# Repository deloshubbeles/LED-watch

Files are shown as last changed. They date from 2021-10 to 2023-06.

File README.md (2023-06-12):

# LED Watch

### Objective
To display the time and day of week on multiplexed LEDs with button presses, plus more.

**Other intended functionality (yet to be implemented)**
- Low power sleep mode to conserve power when inactive
- Flash low battery warning LED when battery voltage drops too low
- Display LEDs at different brightnesses depending on time of day or button pressed (e.g., brighter in daylight, dimmer at night)
- Stopwatch
- Countdown timer

### Displaying the time
time

### Components
- [ATmega328P-MMHR (28-pin VQFN)](https://ww1.microchip.com/downloads/en/DeviceDoc/ATmega48A-PA-88A-PA-168A-PA-328-P-DS-DS40002061B.pdf)
- [M41T62 (8 pin LCC) real time clock](https://www.st.com/resource/en/datasheet/m41t62.pdf)
- 34 multiplexed LEDs (18 red, 12 blue, 4 white)
- CR2016 coin cell battery (~90mAh) and battery holder
- 2 x SPST tactile switches

### Schematic


### PCB layers:
Watch layers

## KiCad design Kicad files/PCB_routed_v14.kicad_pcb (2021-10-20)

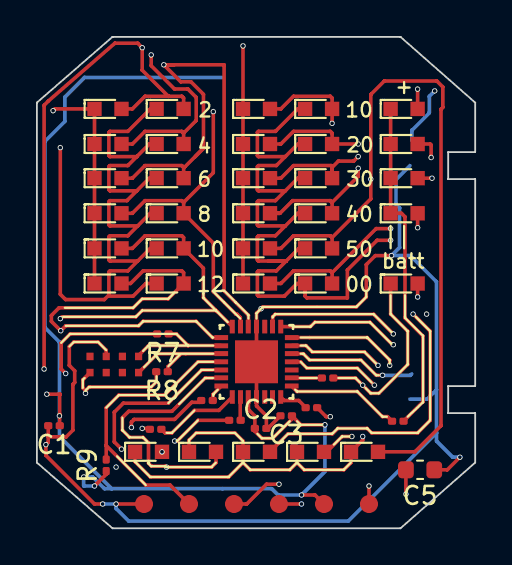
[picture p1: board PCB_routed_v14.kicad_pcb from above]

Board: 4 copper layers, 24.3 x 27.3 mm, 53 parts (0 on the bottom side), 28 nets.

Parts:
BAT1: CR2016
C1, C3: 100nF; C_0201_0603Metric
C2: 10nF; C_0201_0603Metric
C5: 22uF; C_0603_1608Metric
D1, D2, D3, D4, D5, D6, D7, D8, D9, D10, D11, D12: RED_HR; LED_0603
D13, D14, D15, D16, D17, D18, D19, D20, D21, D22, D23, D24: BLUE_MIN; LED_0603
D25, D26, D27, D28: WHITE_+MIN; LED_0603
D29, D30, D31, D32, D33: RED_DAY; LED_0603
D34: RED_BATT; LED_0603
IC1: M41T62LC6F; LCC90P230X50X80-8N
J1: ICSP-6; ICSP
R1, R2, R6: 2K5; R_0201_0603Metric
R3, R4: 1K5; R_0201_0603Metric
R5: 1K33; R_0201_0603Metric
R7, R8, R9: 10K; R_0201_0603Metric
SW1, SW2: SW_SPST; Switch_SPSTnew
U1: ATmega328-MMH; QFN45P400X400X100-29N

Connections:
/COL_0: R1.1, U1.28
/COL_1: R2.1, U1.1
/COL_2: R3.1, U1.2
/COL_3: R4.1, U1.7
/COL_4: R5.1, U1.8
/COL_5: R6.1, U1.9
/ROW_0: D1.2, D7.2, D13.2, D19.2, D25.2, D29.2, U1.26
/ROW_1: D2.2, D8.2, D14.2, D20.2, D26.2, D30.2, U1.27
/ROW_2: D3.2, D9.2, D15.2, D21.2, D27.2, D31.2, U1.19
/ROW_3: D4.2, D10.2, D16.2, D22.2, D28.2, D32.2, U1.20
/ROW_4: D5.2, D11.2, D17.2, D23.2, D33.2, U1.21
/ROW_5: D6.2, D12.2, D18.2, D24.2, D34.2, U1.22
GND: BAT1.Neg1, C1.2, C2.2, C3.2, C5.1, IC1.3, J1.6, SW1.2, SW2.2, U1.4, U1.18, U1.29
unnamed: BAT1.Pos1, C1.1, C2.1, C3.1, C5.2, IC1.5, J1.2, R7.2, R8.2, R9.1, U1.3, U1.16
unnamed: D1.1, D2.1, D3.1, D4.1, D5.1, D6.1, R1.2
unnamed: D7.1, D8.1, D9.1, D10.1, D11.1, D12.1, R2.2
unnamed: D13.1, D14.1, D15.1, D16.1, D17.1, D18.1, R3.2
unnamed: D19.1, D20.1, D21.1, D22.1, D23.1, D24.1, R4.2
unnamed: D25.1, D26.1, D27.1, D28.1, R5.2
unnamed: D29.1, D30.1, D31.1, D32.1, D33.1, D34.1, R6.2
unnamed: IC1.1, R7.1, U1.23
unnamed: IC1.8, R8.1, U1.24
unnamed: J1.1, U1.14
unnamed: J1.3, U1.15
unnamed: J1.4, U1.13
unnamed: J1.5, R9.2, U1.25
unnamed: SW1.1, U1.11
unnamed: SW2.1, U1.12

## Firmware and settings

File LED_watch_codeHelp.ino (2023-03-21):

/* LED WATCH

Two button LED watch with the aim of having the following functions (^incomplete):
  - Time and day of the week (almost but not quite)
  - Light (4 white LEDs)
  - ^Multi button press functionality
  - ^Low power / deep sleep
  - ^Low battery warning
  - ^Stopwatch (start, stop, reset)
  - ^Timer (countdown from a set duration)

MCU: Microchip ATmega328p
RTC: M41T62
*/

/// Libraries
#include "Wire.h"                /// I2C connections
#include "M41T62.h"              /// M41T62 real time clock
#include "PinChangeInterrupt.h"  /// pin change interrupt
#include "LowPower.h"            /// low power sleep
#include "OneButton.h"           /// multi-button functionality
RTC_M41T62 RTC;                  /// real time clock

#define NUM_COL 6   /// columns are anodes
#define NUM_ROW 6   /// rows are cathodes
#define COL_ON LOW  /// the following four lines of code control swtiching the multiplexed LEDs on and off
#define COL_OFF HIGH
#define ROW_ON HIGH
#define ROW_OFF LOW

const int colLED[NUM_COL] = { 2, 3, 4, 5, 6, 7 };      /// pins for anode (+) connections on ATmega328p, columns in LED matrix
const int rowLED[NUM_ROW] = { 0, 1, A0, A1, A2, A3 };  /// pins for cathode (-) connections on ATmega328p, rows in LED matrix

const int button1 = 9;   /// pin for button 1
const int button2 = 10;  /// pin for button 2

volatile int hourRow;
volatile int hourColumn;
volatile int minuteRow;
volatile int minuteColumn;
volatile int minRemain;
volatile int wkDay;

int minuteRemainder;
int weekday;
int lastButtonState = LOW;  // the previous reading from the input pin

uint8_t display[NUM_ROW][NUM_COL];  // this array holds the current image to display

unsigned long previousMillis = 0;
unsigned long previousMillisT = 0;
unsigned long lastDebounceTime = 0;  // the last time the output pin was toggled
unsigned long debounceDelay = 50;    // the debounce time; increase if the output flickers
unsigned long onTime = 20 * 1000;    /// duration time is displayed before going to deep sleep
unsigned long sleepTimer = 0;        /// keep time of how long watch has been awake

const long interval1 = 400;  /// duration of button 1 function
const long interval2 = 200;  /// duration of button 2 function

bool myFlag1 = false;  /// create flag1 for pin change interrupt
bool myFlag2 = false;  /// create flag2 for pin change interrupt

//OneButton button1(9, true);
//OneButton button2(10, true);

/// - - - - - - - - - - - - - - - - - - - - - - - - - - - - - - - - - - - - - -
/// - - - - - - - - - - - - - - - setup + loop - - - - - - - - - - - - - - - -

/// No access to serial monitor

void setup() {
  pinMode(button1, INPUT_PULLUP);            /// button1 pulled LOW when pressed
  pinMode(button2, INPUT_PULLUP);            /// button2 pulled LOW when pressed
  Wire.begin();                              /// I2C communication with the RTC
  RTC.begin();                               /// start RTC
  RTC.adjust(DateTime(__DATE__, __TIME__));  /// set RTC time to computer time

  for (int i = 0; i < NUM_COL; i++)  /// set all column pins to OUTPUT and OFF
  {
    pinMode(colLED[i], OUTPUT);        /// set column LEDs to output
    digitalWrite(colLED[i], COL_OFF);  /// turn all columns off
  }
  for (int j = 0; j < NUM_ROW; j++)  /// set all row pins to OUTPUT and OFF
  {
    pinMode(rowLED[j], OUTPUT);        /// set row LEDs to output
    digitalWrite(rowLED[j], ROW_OFF);  /// turn all rows off
  }
  attachPCINT(digitalPinToPCINT(button1), setFlag1, CHANGE);  /// interrupt when button 1's state changes
  attachPCINT(digitalPinToPCINT(button2), setFlag2, CHANGE);  /// interrupt when button 2's state changes

  /*
  /// link the button 1 functions
  button1.attachClick(singleClick1);
  button1.attachDoubleClick(doubleClick1);
  button1.attachMultiClick(multiClick1);
  button1.attachLongPressStart(pressStart1);
  button1.attachLongPressStop(pressStop1);
  button1.attachDuringLongPress(longPress1);

  /// link the button 2 functions
  button2.attachClick(singleClick2);
  button2.attachDoubleClick(doubleClick2);
  button2.attachMultiClick(multiClick2);
  button2.attachLongPressStart(pressStart2);
  button2.attachLongPressStop(pressStop2);
  button2.attachDuringLongPress(longPress2);
*/
}

void loop() {
  /// If the switch changed, due to noise or pressing:
  if (digitalRead(button1) != lastButtonState) {
    /// reset the debouncing timer
    lastDebounceTime = millis();

    if (myFlag1 == true)  /// if myFlag1 is true, display time
    {
      displayTime();
      unsigned long currentMillis = millis();           /// set the millis riiiiight now!
      if (currentMillis - previousMillis >= interval1)  /// if now minus the time when the next step is over is longer than <interval>
      {
        allOff();
        previousMillis = currentMillis;
        myFlag1 = false;  /// flag off
      }
    }
  }

  /// If the switch changed, due to noise or pressing:
  if (digitalRead(button2) != lastButtonState) {
    /// reset the debouncing timer
    lastDebounceTime = millis();

    if (myFlag2 == true)  /// if myFlag2 is true, display time
    {
      light();
      //displayTimeBright();
      unsigned long currentMillisT = millis();            /// set the millis riiiiight now!
      if (currentMillisT - previousMillisT >= interval2)  /// if now minus the time when the next step is over is longer than <duration>
      {
        allOff();
        previousMillisT = currentMillisT;
        myFlag2 = false;  /// flag off
      }
    }
  }

  if (myFlag1 == false && myFlag2 == false)  /// if myFlag1 and myFlag2 are false, go to sleep
  {
    LowPower.powerDown(SLEEP_FOREVER, ADC_OFF, BOD_OFF);  /// Zzzzzzz
  }
}

/// - - - - - - - - - - - - - - - - - - - - - - - - - - - - - - - - - - - - - -
/// - - - - - - - - - - - - - - - button functions - - - - - - - - - - - - - - -

void setFlag1() {
  myFlag1 = true;
}

void setFlag2() {
  myFlag2 = true;
}

/*
/// button1
void singleClick1() {  /// function called when button pressed once
}
void doubleClick1() {  /// function called when button was pressed two times in a short timeframe
}
void multiClick1() {  /// function called when button pressed multiple (>2) times in a short timeframe
}
void pressStart1() {  /// function called when button held down for one second or more
}
void pressStop1() {  /// function called when button released after long hold
}

/// button2
void singleClick2() {  /// function called when button pressed once
}
void doubleClick2() {  /// function called when button was pressed two times in a short timeframe
}
void multiClick2() {  /// function called when button pressed multiple (>2) times in a short timeframe
}
void pressStart2() {  /// function called when button held down for one second or more
}
void pressStop2() {  /// function called when button released after long hold
}
*/

/// - - - - - - - - - - - - - - - - - - - - - - - - - - - - - - - - - - - - - -
/// - - - - - - - - - - - - - - - time functions - - - - - - - - - - - - - - - -

void getTime() {
  static int lastMinute = -1;
  DateTime now = RTC.now();  /// set "now" from the computer's time

  if (now.minute() == lastMinute)
    return;  /// No need to re-calculate if the time has not changed

  lastMinute = now.minute();
  int hour = now.hour() % 12;
  int minute = now.minute() - 5;
  weekday = now.dayOfWeek() - 1;

  /// set hour
  if (hour == 0)
    hour = 12;
  hourRow = (hour - 1) / 2;
  hourColumn = (hour - 1) % 2;

  /// set minute --- something not quite right here
  minuteRow = minute / 10;
  minuteColumn = 2 + ((minute % 10) > 5);
  // minuteColumn = 2 + ((minute - 1) / 5)  % 2;
  minuteRemainder = minute % 5;
}

/// - - - - - - - - - - - - - - - - - - - - - - - - - - - - - - - - - - - - - -
/// - - - - - - - - - - - - - - - display functions - - - - - - - - - - - - - -

/// turn on specific LEDs
inline void ledOn(int row, int col) {
  digitalWrite(rowLED[row], HIGH);  /// row pin to +3V
  digitalWrite(colLED[col], LOW);   /// column pin to 0V
  //allOff();
}

/// turn off specific LEDs
inline void ledOff(int row, int col) {
  digitalWrite(rowLED[row], LOW);   /// row pin to 0V
  digitalWrite(colLED[col], HIGH);  /// column pin to +3V
}

/// turn on all LEDs
void allOn() {
  for (int i = 0; i < NUM_COL; i++) {
    digitalWrite(colLED[i], COL_ON);  /// all columns to 3V
  }
  for (int j = 0; j < NUM_ROW; j++) {
    digitalWrite(rowLED[j], ROW_ON);  /// all rows to 3V
  }
}

/// turn off all LEDs
void allOff() {
  for (int i = 0; i < NUM_ROW; i++) {
    digitalWrite(rowLED[i], ROW_OFF);  /// all row pins to 0V
  }
  for (int j = 0; j < NUM_COL; j++) {
    digitalWrite(colLED[j], COL_OFF);  /// all column pins to 0V
  }
}

void displayTime() {  /// still slight flicker to the LEDs, especially when viewed up close. Decreasing the delay reduces the flicker but dims the LEDs
  getTime();
  allOff();
  ledOn((int)hourRow, (int)hourColumn);
  delayMicroseconds(150);
  ledOff((int)hourRow, (int)hourColumn);
  ledOn((int)minuteRow, (int)minuteColumn);
  delayMicroseconds(150);
  ledOff((int)minuteRow, (int)minuteColumn);
  ledOn((int)minuteRemainder, 4);
  delayMicroseconds(100);
  ledOff((int)minuteRemainder, 4);
  ledOn((int)weekday, 5);
  delayMicroseconds(150);
  ledOff((int)weekday, 5);
}

void displayTimeBright() {  /// the LEDs are much brighter than displayTime(), but additional/wrong LEDs are turned on aswell for some reason
  getTime();
  ledOn((int)hourRow, (int)hourColumn);
  ledOn((int)minuteRow, (int)minuteColumn);
  ledOn((int)minuteRemainder, 4);
  ledOn((int)weekday, 5);
}

void light()  /// turns on four white LEDs
{
  ledOn(0, 4);
  ledOn(1, 4);
  ledOn(2, 4);
  ledOn(3, 4);
}

/// - - - - - - - - - - - - - - - - - - - - - - - - - - - - - - - - - - - - - -
/// - - - - - - - - - - - - - - - - power functions - - - - - - - - - - - - - -

const long InternalReferenceVoltage = 1062;  /// Adjust this value to your board's specific internal BG voltage

/// results are Vcc * 100, so 3.3V would be 330?
int getBandgap() {
  /// REFS0 : Selects AVcc external reference
  /// MUX3 MUX2 MUX1 : Selects 1.1V (VBG)
  ADMUX = bit(REFS0) | bit(MUX3) | bit(MUX2) | bit(MUX1);
  ADCSRA |= bit(ADSC);           /// start conversion
  while (ADCSRA & bit(ADSC)) {}  /// wait for conversion to complete
  int results = (((InternalReferenceVoltage * 1024) / ADC) + 5) / 10;
  return results;
  if (results > 0.0000001) {
    allOff();
    digitalWrite(rowLED[5], HIGH);  /// ON - cathode pin to +5V
    digitalWrite(colLED[5], LOW);   /// ON - anode pin to 0V
    delay(100);
    digitalWrite(rowLED[5], LOW);   /// OFF - cathode pin to 0V
    digitalWrite(colLED[5], HIGH);  /// OFF - anode pin to 5V
    delay(100);
  }
}

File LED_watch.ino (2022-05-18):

/// Displaying time (5 minutes fast) with consistent brightness
/// No flicker using TIMER_FREQ_HZ values of 1.5k to 10k, being dimmer and brighter, respectively.

#define TIMER_INTERRUPT_DEBUG         2
#define _TIMERINTERRUPT_LOGLEVEL_     0
#define USE_TIMER_1     true

#include "Wire.h"                    /// I2C library
#include "M41T62.h"                  /// RTC library for M41T62 - NB: Use "dayOfWeek"
#include "LowPower.h"                /// Low power library for deep sleep mode
#include <TimerInterrupt.h>          /// Library for timer interrupt
#include "OneButton.h"               /// Library for button functionality
RTC_M41T62 RTC;

#define TIMER_FREQ_HZ        10000.0        /// ~15k starts to act funny, 10k nice and bright, 1.5k dim but not flickering, 500 starts to flicker

#define NUM_COL       6                /// Columns are anodes
#define NUM_ROW       6                /// Rows are cathodes
#define COL_ON    LOW                 /// badge code has these four inverted
#define COL_OFF   HIGH
#define ROW_ON    HIGH
#define ROW_OFF   LOW

const int button1 = 9;
const int button2 = 10;

const int colLED[NUM_COL] = {2, 3, 4, 5, 6, 7};          /// pins for anode (+) connections on ATmega328, columns in LED matrix
const int rowLED[NUM_ROW] = {0, 1, A0, A1, A2, A3};      /// pins for cathode (-) connections on ATmega328, rows in LED matrix

const int hourRows = 6;
const int hourCols = 2;

int rowPin = 6;
int colPin = 6;
volatile int hourRow;
volatile int hourColumn;
volatile int minuteRow;
volatile int minuteColumn;
volatile int minRemain;
volatile int wkDay;
int minuteRemainder;
int weekday;

int hourArray[hourRows][hourCols] = {{1, 2}, {3, 4}, {5, 6}, {7, 8}, {9, 10}, {11, 12}};

/// - - - - - - - - - - - SETUP + LOOP - - - - - - - - - - - - - - - -

/// No access to serial monitor

void setup() {
  Wire.begin();                                 /// I2C communication with the RTC
  pinMode(button1, INPUT_PULLUP);               /// button1 pulled LOW when pressed
  pinMode(button2, INPUT_PULLUP);               /// button2 pulled LOW when pressed
  RTC.begin();                                  /// start RTC
  RTC.adjust(DateTime(__DATE__, __TIME__));     /// set RTC time to computer time

  for (int i = 0; i < NUM_COL; i++)              /// set all column pins to OUTPUT and OFF
  {
    pinMode(colLED[i], OUTPUT);                 /// output
    digitalWrite(colLED[i], COL_OFF);           /// turn off
  }
  for (int j = 0; j < NUM_ROW; j++)              /// set all row pins to OUTPUT and OFF
  {
    pinMode(rowLED[j], OUTPUT);                 /// output
    digitalWrite(rowLED[j], ROW_OFF);           /// turn off
  }
  ITimer1.init();                               /// initialise timer 1
  ITimer1.attachInterrupt(TIMER_FREQ_HZ, TimerHandler);
}

void loop() {
  getTime();
}

void TimerHandler() {
  displayTime();
  //cylon();
  //processing();
  //allOn();
  //lowBattery();
}

/// - - - - - - - - - - - display functions - - - - - - - - - - - - - - - -

void allOn() {                            /// turns on all LEDs
  /// all cathode pins to 5V
  for (int i = 0; i < NUM_COL; i++) {
    digitalWrite(colLED[i], COL_ON);
  }
  /// all cathode pins to 0V
  for (int j = 0; j < NUM_ROW; j++) {
    digitalWrite(rowLED[j], ROW_ON);
  }
}

void allOff() {                             /// turns off all LEDs
  /// all cathode pins to 0V
  for (int i = 0; i < rowPin; i++) {
    digitalWrite(rowLED[i], ROW_OFF);
  }
  /// all anode pins to +5V
  for (int j = 0; j < 1; j++) {
    digitalWrite(colLED[j], COL_OFF);
  }
}

inline void ledOn(int row, int col) {      /// turns on specific LEDs
  digitalWrite(rowLED[row], HIGH);        /// cathode pin to +5V
  digitalWrite(colLED[col], LOW);         /// anode pin to 0V
  //allOff();
}

inline void ledOff(int row, int col) {      /// turns on specific LEDs
  digitalWrite(rowLED[row], LOW);        /// cathode pin to +5V
  digitalWrite(colLED[col], HIGH);         /// anode pin to 0V
}

void ledOnCylon(int row, int col)                /// turns on specfic LEDs
{
  allOff();
  digitalWrite(rowLED[row], HIGH);        /// cathode pin to +5V
  digitalWrite(colLED[col], LOW);         /// anode pin to 0V
  //digitalWrite(rowLED[row], LOW);
  //digitalWrite(colLED[col], HIGH);
}

/// - - - - - - - - - - - - - - - time functions - - - - - - - - - - - - - - - -

void getTime()
{
  static int lastMinute = -1;
  DateTime now = RTC.now();

  if (now.minute() == lastMinute)
    return;  /// No need to re-calculate if the time has not changed

  lastMinute = now.minute();

  int hour = now.hour() % 12;
  int minute = now.minute();
  weekday = now.dayOfWeek() - 1;

  /// set hour
  if (hour == 0)
    hour = 12;
  hourRow = (hour - 1) / 2;
  hourColumn = (hour - 1) % 2;

  /// set minute
  minuteRow = minute / 10;
  minuteColumn = 2 + ((minute - 1) / 5)  % 2;
  minuteRemainder = minute % 5;
}

void displayTime() {
  ledOn((int)hourRow, (int)hourColumn);
  ledOff((int)hourRow, (int)hourColumn);
  ledOn((int)minuteRow, (int)minuteColumn);
  ledOff((int)minuteRow, (int)minuteColumn);
  ledOn((int)minuteRemainder, 4);
  ledOff((int)minuteRemainder, 4);
  ledOn(weekday, 5);
  ledOff(weekday, 5);
}

/// - - - - - - - - - - - pattern functions - - - - - - - - - - - - - - - -

void cylon() /// row (x) then column (y) -- runs across days of the week
{
  for (int i = 0; i < 5; i++)
  {
    ledOnCylon(i, 5);
    delay(1000);
  }
  for (int j = 4; j >= 0; j--)
  {
    ledOnCylon(j, 5);
    delay(1000);
  }
}

void processing()
{
  for (int i = random(0, 6); i < NUM_ROW; i++)
  {
    for (int j = random(0, 6); j < NUM_COL; j++) {
      digitalWrite(rowLED[i], HIGH);
      digitalWrite(colLED[j], LOW);
      delay(1000);
      digitalWrite(rowLED[j], LOW);
      digitalWrite(colLED[i], HIGH);
    }
  }
  for (int j = random(1, 6); j < NUM_ROW; j++)
  {
    digitalWrite(rowLED[j], HIGH);
    digitalWrite(colLED[j], HIGH);
    delay(1000);
  }
  delay(2500);
}

/// - - - - - - - - - - - - power functions - - - - - - - - - - - - - - -

const long InternalReferenceVoltage = 1062;  /// Adjust this value to your board's specific internal BG voltage

/// results are Vcc * 100, so 5V would be 500
int getBandgap ()
{
  /// REFS0 : Selects AVcc external reference
  /// MUX3 MUX2 MUX1 : Selects 1.1V (VBG)
  ADMUX = bit (REFS0) | bit (MUX3) | bit (MUX2) | bit (MUX1);
  ADCSRA |= bit( ADSC );  /// start conversion
  while (ADCSRA & bit (ADSC))
  { }  /// wait for conversion to complete
  int results = (((InternalReferenceVoltage * 1024) / ADC) + 5) / 10;
  return results;
} /// end of getBandgap
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

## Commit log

2021-10-20 Add files via upload
    PCB layers and circuitboard schematic
2021-11-01 Latest code for LED watch
    Added code for Low power mode and interrupt but yet to test on watch
2021-11-01 Update minute LED calculations to include the remainder
2021-11-05 #2 Fix minute calculation by separating column and row logic
    [LED_watch.ino]
2021-12-04 Add files via upload
    I changed the code to something like the Hackerspace’s Phatbadge so it shows each column at a time, for equally timed intervals. Also changed getting the time in each function (DateTime now = RTC.now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
2022-01-07 #4 Use minute % 5 to get minutes 1-4 and 6-9 as positive integers 1-4, then take off one when setting the zero indexed LED
2022-05-18 LED watch running with timer interrupt
2022-05-18 Latest code using timer interrupts
2022-05-18 Latest code displaying with timer interrupt
2022-10-23 Update and rename Low-Power/README.md to Libraries/README.md
2022-10-28 Latest watch code
    Using pin change interrupts
